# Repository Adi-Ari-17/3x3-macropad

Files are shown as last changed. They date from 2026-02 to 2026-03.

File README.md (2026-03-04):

# 3×3 Macropad

A simple, open-source 9-key macro pad powered by Seeeduino XIAO RP2040.

## Features
- 3×3 ortholinear key matrix
- QMK firmware with layer support
- USB-C charging & programming
- 3D-printable sandwich case

## Build Time
Estimated: 30–45 minutes

## Parts Required
See `BOM.csv` for full component list.

## Documentation
- [BUILD_GUIDE.md](BUILD_GUIDE.md) – Assembly instructions  
- [QMK_GUIDE.md](QMK_GUIDE.md) – Firmware flashing & customization

## Case

This is an example of a fully built case with the a simple green rectangle to show the pcb
Screenshot 2026-02-18 at 1 37 45 PM

It is a simple case disigned for a 9 keys in a 3by3 format close to eachother

I am pretty proud of this design and I learned to use tags to stop it from getting messy :)
Screenshot 2026-02-18 at 2 50 03 PM

My PCB is a little unproffesional but I learned to use Vias to stop my wiring to go all over the place.
Screenshot 2026-02-18 at 2 51 27 PM

##PCB

This is the first PCB I have ever made and I learned a lot through this experience

I used a matrix in my design schematic as shown here
Screenshot 2026-02-18 at 2 50 03 PM

I am pretty proud of this being my first design and I especially learned to use tags to stop it from getting messy :)

My PCB is a little unproffesional but I learned to use Vias to stop my wiring to go all over the place.
Screenshot 2026-02-18 at 2 51 27 PM

## Files
- `kicad/` – KiCad schematic & PCB design
- `firmware/` – QMK firmware source
- `case/` – 3D printable case files (.STEP)
- `images/` – Reference photos

## Hack Club Hackpad Submission
This project is designed for the [Hack Club Hackpad](https://hackpad.hackclub.com/) YSWS program.

## License
MIT License – See [LICENSE](LICENSE)

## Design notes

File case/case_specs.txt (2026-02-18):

3x3 Macropad Case Specifications
=================================

Print Settings:
- Material: PLA or PETG
- Layer Height: 0.2mm (0.1mm for details)
- Infill: 20%
- Support: Yes (for overhangs >45°)
- Wall Thickness: 1.5mm
- No raft needed

Dimensions (approx):
- Length: ~70mm
- Width: ~70mm
- Height: 13mm (3mm base + 10mm walls)

Mounting:
- Heatset inserts: M3 (4.7mm holes, 4mm deep)
- Screw type: M3x4mm
- Count: 4 mounting points

Post-Processing:
- Remove supports carefully
- Sand edges with 180–220 grit
- Optional: Paint or coat with clear gloss finish

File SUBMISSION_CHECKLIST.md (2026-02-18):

# Submission Checklist & Final Steps

## ✅ Pre-Submission Verification

Your 3×3 macropad submission package is **complete** with:

### PCB Design
- ✅ Schematic: `kicad/3x3_macropad.kicad_sch`
- ✅ PCB Layout: `kicad/3x3_macropad.kicad_pcb`
- ✅ Gerber Files: `kicad/gerbers/3by3PCB.zip` (7 files: 5 layers + PTH/NPTH drills)

### Case Design
- ✅ STEP File: `case/case_assembly.step` (for Hack Club submission)
- ✅ STL File: `case/iKeyMacroPadCase.stl` (for 3D printing reference)

### QMK Firmware (Seeeduino XIAO RP2040)
- ✅ Config: `firmware/config.h` (matrix pins, USB IDs)
- ✅ Layout: `firmware/3x3_macropad.h`
- ✅ Rules: `firmware/rules.mk`
- ✅ Keymaps: `firmware/keymaps/default/keymap.c` (2 layers ready)
- ✅ Info: `firmware/info.json` (QMK Configurator compatible)

### Documentation
- ✅ README.md – Project overview & features
- ✅ BOM.csv – Complete bill of materials
- ✅ BUILD_GUIDE.md – Step-by-step assembly
- ✅ QMK_GUIDE.md – Firmware flashing instructions

---

## 🚀 Final Steps to Submit

### Step 1: Push to GitHub

```bash
cd /Users/adityan/projects/workspace/ikey

# Set your GitHub username and email (one-time)
git config --global user.name "Your Name"
git config --global user.email "your.email@example.com"

# Add GitHub remote (replace USERNAME with your GitHub username)
git remote add origin https://github.com/USERNAME/3x3-macropad.git

# Push to GitHub
git branch -M main
git push -u origin main
```

### Step 2: Verify on GitHub
- Go to `https://github.com/USERNAME/3x3-macropad`
- Confirm all files are visible:
  - kicad/ folder with schematic, PCB, gerbers
  - firmware/ folder with config & keymaps
  - case/ folder with STEP file
  - README.md, BOM.csv, BUILD_GUIDE.md, QMK_GUIDE.md

### Step 3: Test Gerbers on JLCPCB (Optional but Recommended)
```bash
# Visit https://jlcpcb.com
# Instant Quote → Upload kicad/gerbers/3by3PCB.zip
# You should see a visual PCB preview with all layers
# If preview looks good, gerbers are correct!
```

### Step 4: Submit to Hack Club Hackpad
1. Navigate to **https://hackpad.hackclub.com**
2. Click **Submit Your Macropad**
3. Fill out the form:
   - **Project Name:** 3x3 Macropad (or your creative name!)
   - **GitHub URL:** `https://github.com/USERNAME/3x3-macropad`
   - **Description:** "A simple, open-source 9-key macro pad with QMK firmware and 3D-printable case"
   - **Email:** Your email address
   - **Slack Handle:** Your Hack Club Slack username (optional)
4. Click **Submit**

### Step 5: Wait for Approval
- Hack Club team reviews submissions **within 1–3 weeks**
- They validate:
  - All required files present (schematic, PCB, case, firmware)
  - Design is novel/custom
  - Documentation is clear
  - BOM is accurate

### Step 6: Upon Approval, You Receive:
- 💰 **$15 JLCPCB credit** (covers ~5 PCBs)
- 📦 **Free component kit** (switches, diodes, XIAO, etc.)
- 🖨️ **Free 3D-printed case** from Printing Legion
- 📧 Email with all instructions & shipping details

---

## 📋 Project Statistics

```
Files:        18 total
Firmware:     6 QMK files (config, layout, keymap, rules)
Documentation: 4 markdown guides + BOM
Commits:      4 (organized workflow)
Total Size:   ~1.2 MB
```

---

## ✨ Next: After Approval

1. **Order PCB:** Use $15 JLCPCB credit to order your first board
2. **Get Components:** Hack Club ships the free kit
3. **3D Print Case:** Printing Legion handles free case production
4. **Build It!:** Solder components, flash firmware, assemble case
5. **Celebrate:** You've built a keyboard! 🎉

---

### Questions?
- **#hackpad** on Hack Club Slack
- [Hack Club Hackpad Guide](https://blueprint.hackclub.com/hackpad)
- [QMK Docs](https://docs.qmk.fm/)

**You're all set! Ready to push to GitHub and submit? 🚀**

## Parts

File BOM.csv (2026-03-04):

Quantity | Component | Value | Supplier | Notes
9 | Diode | 1N4148WS | AliExpress/JLCPCB | SOD-123 SMD
1 | Microcontroller | Seeeduino XIAO RP2040 | Seeed Studio | RP2040 variant
1 | USB Connector | USB Type-C Receptacle | JLCPCB | USB-C 16-pin
1 | Case (printed) | PLA/PETG 3D print | Printing Legion | 0.2mm layer height
9 | Cherry MX Switches | Various | MechKeys/Astro | Nothing

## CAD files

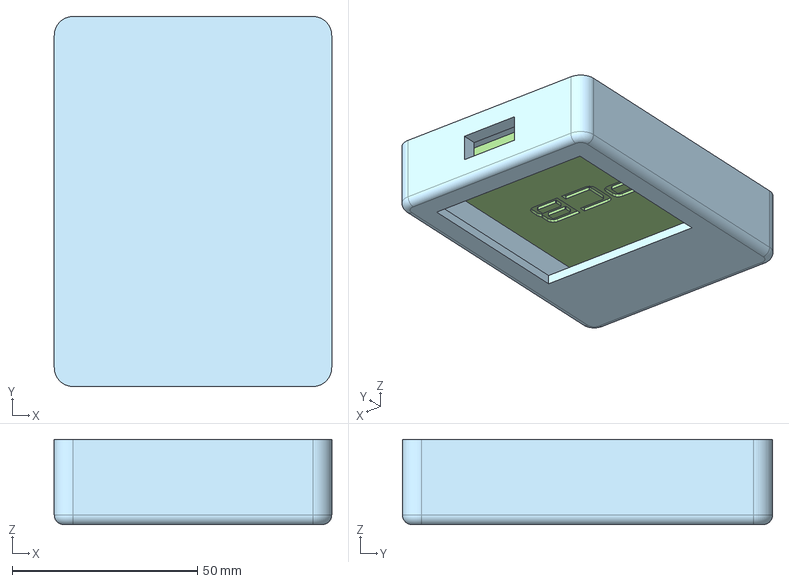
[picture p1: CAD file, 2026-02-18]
case/case_assembly.step
75.0 x 100.0 x 23.0 mm

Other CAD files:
case/iKeyMacroPadCase.stl

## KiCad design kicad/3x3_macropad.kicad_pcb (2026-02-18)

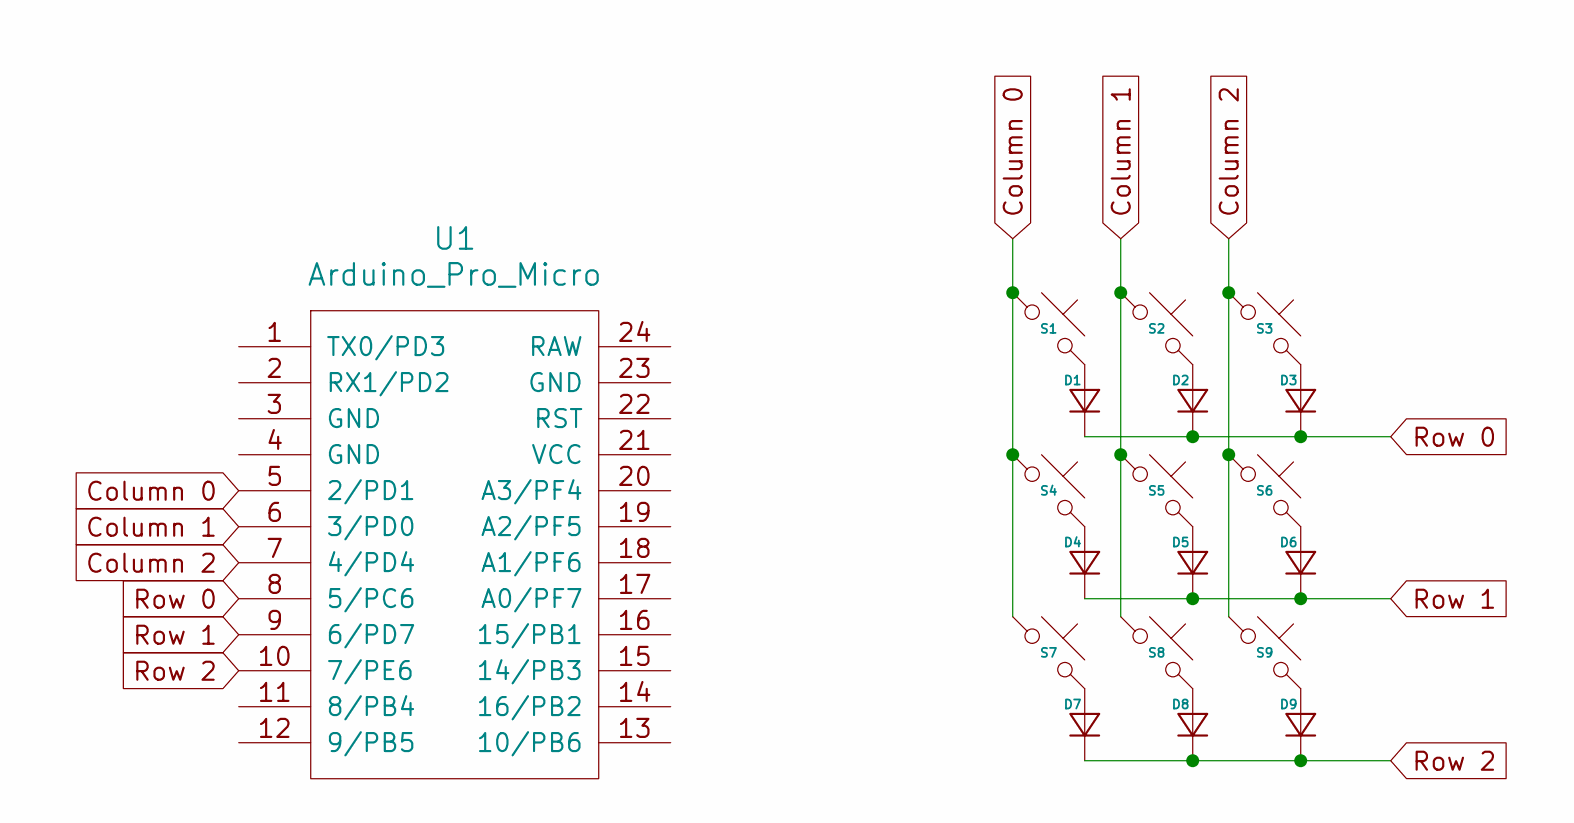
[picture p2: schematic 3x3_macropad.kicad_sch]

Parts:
D1, D2, D3, D4, D5, D6, D7, D8, D9: Diode_DO-35
S1, S2, S3, S4, S5, S6, S7, S8, S9: MX_PCB_1.00u
U1: Arduino_Pro_Micro

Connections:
Column 0: S1.1, S4.1, S7.1, U1.5 (2/PD1); also elsewhere on the board
Column 1: S2.1, S5.1, S8.1, U1.6 (3/PD0); also elsewhere on the board
Column 2: S3.1, S6.1, S9.1, U1.7 (4/PD4); also elsewhere on the board
unnamed: D1.2 (A), S1.2
unnamed: D2.2 (A), S2.2
unnamed: D3.2 (A), S3.2
unnamed: D4.2 (A), S4.2
unnamed: D5.2 (A), S5.2
unnamed: D6.2 (A), S6.2
unnamed: D7.2 (A), S7.2
unnamed: D8.2 (A), S8.2
unnamed: D9.2 (A), S9.2
Row 0: D1.1 (K), D2.1 (K), D3.1 (K), U1.8 (5/PC6); also elsewhere on the board
Row 1: D4.1 (K), D5.1 (K), D6.1 (K), U1.9 (6/PD7); also elsewhere on the board
Row 2: D7.1 (K), D8.1 (K), D9.1 (K), U1.10 (7/PE6); also elsewhere on the board

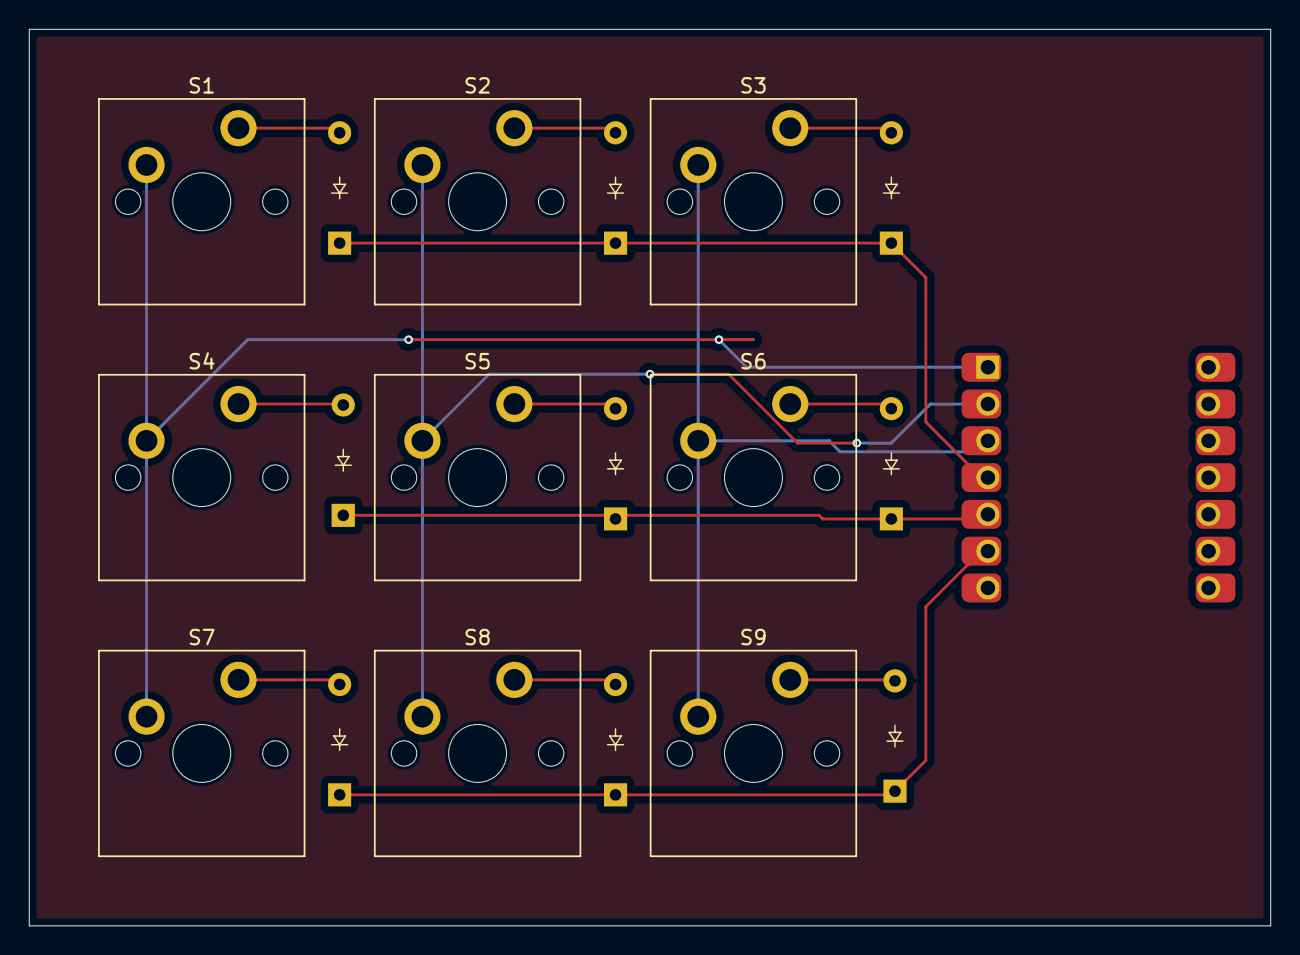
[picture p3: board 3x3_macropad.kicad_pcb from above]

Board: 2 copper layers, 85.7 x 61.9 mm, 19 parts (0 on the bottom side), 15 nets.

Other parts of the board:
U2: MCU_Seeed_XIAO_RP2040; Seeed_XIAO_RP2040

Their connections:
Column 0: U2.1 (PA02_A0_D0); also elsewhere on the board
Column 1: U2.2 (PA4_A1_D1); also elsewhere on the board
Column 2: U2.3 (PA10_A2_D2); also elsewhere on the board
Row 0: U2.4 (PA11_A3_D3); also elsewhere on the board
Row 1: U2.5 (PA8_A4_D4_SDA); also elsewhere on the board
Row 2: U2.6 (PA9_A5_D5_SCL); also elsewhere on the board

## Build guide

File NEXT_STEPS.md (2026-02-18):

# Next Steps – 3×3 Macropad Implementation

## 1. Copy Your KiCad Files
Move your existing KiCad files into the `kicad/` folder:

```bash
cp /path/to/your/3x3_macropad.kicad_sch kicad/
cp /path/to/your/3x3_macropad.kicad_pcb kicad/
cp /path/to/your/3x3_macropad.kicad_pro kicad/
```

## 2. Export Gerber Files for JLCPCB
1. Open `kicad/3x3_macropad.kicad_pcb` in KiCad PCB Editor
2. Go to **File → Plot** (Ctrl+Shift+P)
3. **Plot Options:**
   - Layers: F.Cu, B.Cu, F.SilkS, B.SilkS, Edge.Cuts
   - Output directory: `kicad/gerbers/`
   - Format: Gerber (RS-274X)
4. Click **Plot**
5. Click **Generate Drill File** (Excellon format)
6. Zip all files:
   ```bash
   cd kicad/gerbers
   zip 3x3_macropad.zip *.gbr *.txt
   ```
7. Test preview: Upload to [jlcpcb.com](https://jlcpcb.com) to verify layers

## 3. Export Case STEP File
**Note:** You already have `case/iKeyMacroPadCase.stl` imported.

For Hack Club submission, convert the STL to STEP format:
1. Open `case/iKeyMacroPadCase.stl` in Fusion360
2. Right-click model → **Save as**
3. Select **STEP (.step)** format
4. Save to: `case/case_assembly.step`
5. Verify dimensions in mm
6. Keep both `.stl` (for printing reference) and `.step` (for submission)

## 4. Customize Firmware (Optional)
Edit `firmware/keymaps/default/keymap.c` to customize keys:
- Layer 0: Numbers (default)
- Layer 1: Function keys
- Add more layers as needed

Update `firmware/config.h` if your pin configuration differs from:
- Row pins: GP27, GP26, GP25
- Col pins: GP6, GP7, GP8

## 5. Test Compile Firmware
```bash
cd ~/qmk_firmware
qmk compile -kb yourname/3x3_macropad -km default
```
Should output a `.uf2` file without errors.

## 6. Prepare GitHub
```bash
cd /Users/adityan/projects/workspace/ikey

# Stage all files
git add .

# Commit
git commit -m "Initial 3x3 macropad design, case, and firmware"

# Add remote (replace with your GitHub repo)
git remote add origin https://github.com/yourusername/3x3-macropad.git
git branch -M main
git push -u origin main
```

## 7. Verify Submission Package
Run this checklist:
- [ ] `kicad/3x3_macropad.kicad_sch` exists
- [ ] `kicad/3x3_macropad.kicad_pcb` exists
- [ ] `kicad/gerbers/3x3_macropad.zip` is ready for JLCPCB
- [ ] `case/case_assembly.step` exported from Fusion360
- [ ] `firmware/` has config.h, 3x3_macropad.h, rules.mk, keymaps/default/keymap.c
- [ ] `firmware/` compiles with QMK without errors
- [ ] README.md, BOM.csv, BUILD_GUIDE.md, QMK_GUIDE.md all present
- [ ] GitHub repo is public and linked correctly
- [ ] All files follow MIT License

## 8. Submit to Hack Club
1. Navigate to **[hackpad.hackclub.com](https://hackpad.hackclub.com/)**
2. Fill out submission form:
   - GitHub repo link
   - Macropad name: "3x3 Macropad"
   - Brief description (1–2 sentences)
   - Your email & Slack username
3. Submit!

## 9. After Approval
Hack Club will email you within 1–3 weeks with:
- $15 JLCPCB credit
- Free component kit
- Printing Legion 3D case credit
- Build instructions

## Need Help?
- Ask in **#hackpad** on [Hack Club Slack](https://hackclub.slack.com)
- Check [QMK Docs](https://docs.qmk.fm/)
- See [Hack Club Hackpad Guide](https://blueprint.hackclub.com/hackpad)

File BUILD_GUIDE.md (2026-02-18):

# Build Guide – 3×3 Macropad

## Prerequisites
- Soldering iron & solder (60/40 or lead-free)
- Tweezers & small screwdriver
- Flux (optional but recommended)

## Step-by-Step Assembly

### 1. Prepare the PCB
- Inspect for defects
- Apply flux to pads if needed

### 2. Solder Diodes
- Orientation: Cathode (black line) toward column pin
- Solder one pad, then adjust, then solder second pad

### 3. Solder XIAO Microcontroller
- Align pins carefully
- Solder one corner pin first
- Solder remaining pins

### 4. Solder USB Connector
- Position with pads aligned
- Solder all 5 pins

### 5. Solder Hotswap Sockets
- Insert each socket into pads
- Solder both pads per socket (repeat for all 9)

### 6. Test with Multimeter
- Check for continuity between GND and key pads
- Verify no shorts

### 7. Prepare Case
- Remove supports from 3D-printed parts
- Sand edges smooth
- Insert heatset inserts (if using)

### 8. Assemble Case
- Place PCB in bottom enclosure
- Screw top plate to mounting holes
- Secure side walls

### 9. Install Switches
- Insert 9 switches into hotswap sockets
- Press down firmly until click

### 10. Keycaps
- Add your favorite keycaps
- Enjoy!

## Troubleshooting
- Keys not registering? Check diode orientation & solder joints
- USB not detected? Verify XIAO pins & USB connector solder

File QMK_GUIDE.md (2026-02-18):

# QMK Firmware Guide

## Setup
1. Clone QMK: `git clone https://github.com/qmk/qmk_firmware.git`
2. Install QMK CLI: `brew install qmk/qmk/qmk` (macOS)
3. Clone this repo into QMK keyboards: 
   ```bash
   git clone <this-repo> ~/qmk_firmware/keyboards/yourname/3x3_macropad
   ```

## Compile
```bash
qmk compile -kb yourname/3x3_macropad -km default
```

## Flash
### Using QMK Toolbox (GUI)
1. Download [QMK Toolbox](https://github.com/qmk/qmk_toolbox)
2. Select the `.uf2` file from compilation
3. Put XIAO into bootloader (double-tap reset button)
4. Click Flash

### Using Terminal
```bash
qmk flash -kb yourname/3x3_macropad -km default
```
Then double-tap the XIAO reset button when prompted.

## Customize Keymap
Edit `firmware/keymaps/default/keymap.c`:
- Change keycodes in the layout
- Recompile and flash

Example layer 2 (media controls):
```c
[2] = LAYOUT_ortho_3x3(
    KC_MPRV, KC_MPLY, KC_MNXT,
    KC_VOLD, KC_MUTE, KC_VOLU,
    KC_BRID, KC_BRIU, KC_PAUS
)
```

## Reference
- [QMK Docs](https://docs.qmk.fm/)
- [Keycodes](https://docs.qmk.fm/keycodes)

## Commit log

2026-02-18 Add firmware, documentation, and project structure for 3x3 macropad
    [BOM.csv]
2026-02-18 Add KiCad PCB/schematic and case STL files from ScottoCad
    [3x3_macropad.kicad_pcb, 3x3_macropad.kicad_sch, iKeyMacroPadCase.stl]
2026-02-18 Add Gerber files for JLCPCB PCB manufacturing
2026-02-18 Add Gerber files and STEP case design for Hack Club submission
    [case_assembly.step]
2026-02-20 Map schematic PAxx pins to RP2040 GP# in firmware/config.h
2026-03-04 Update BOM.csv
    Removed hot swappable sockets
    [BOM.csv]
